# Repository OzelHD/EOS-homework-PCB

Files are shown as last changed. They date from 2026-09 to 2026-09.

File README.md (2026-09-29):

# Generation complete!
# EOS Homework Board

This board is a tutorial follow-along for the EOS homework assignment. It is designed to be a simple board that can be used to learn about PCB design and manufacturing. [Layout Video](https://www.youtube.com/watch?v=nkHFoxe0mrU), [PCB video](https://www.youtube.com/watch?v=PlXd3lLZ4vc)
:)
# Include documentation here




The documentation can be very similar to your wiki article

#Getting started

use `git submodule init && git submodule update --remote --recursive` to get the submodules, and then you can use the project as a normal KiCAD project.

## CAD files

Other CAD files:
PCB/Parts/OzelHD-addition-repo/OzelHD-addition-3D_models/QFN-48-1EP_7x7mm_P0.5mm_EP5.6x5.6mm.step
PCB/Parts/OzelHD-addition-repo/OzelHD-addition-3D_models/Crystal_SMD_MicroCrystal_CC8V-T1A-2Pin_2.0x1.2mm.step
PCB/Parts/OzelHD-addition-repo/OzelHD-addition-3D_models/0530480410.stp
PCB/Parts/OzelHD-addition-repo/OzelHD-addition-3D_models/DLF162500LT-5028A1.STEP

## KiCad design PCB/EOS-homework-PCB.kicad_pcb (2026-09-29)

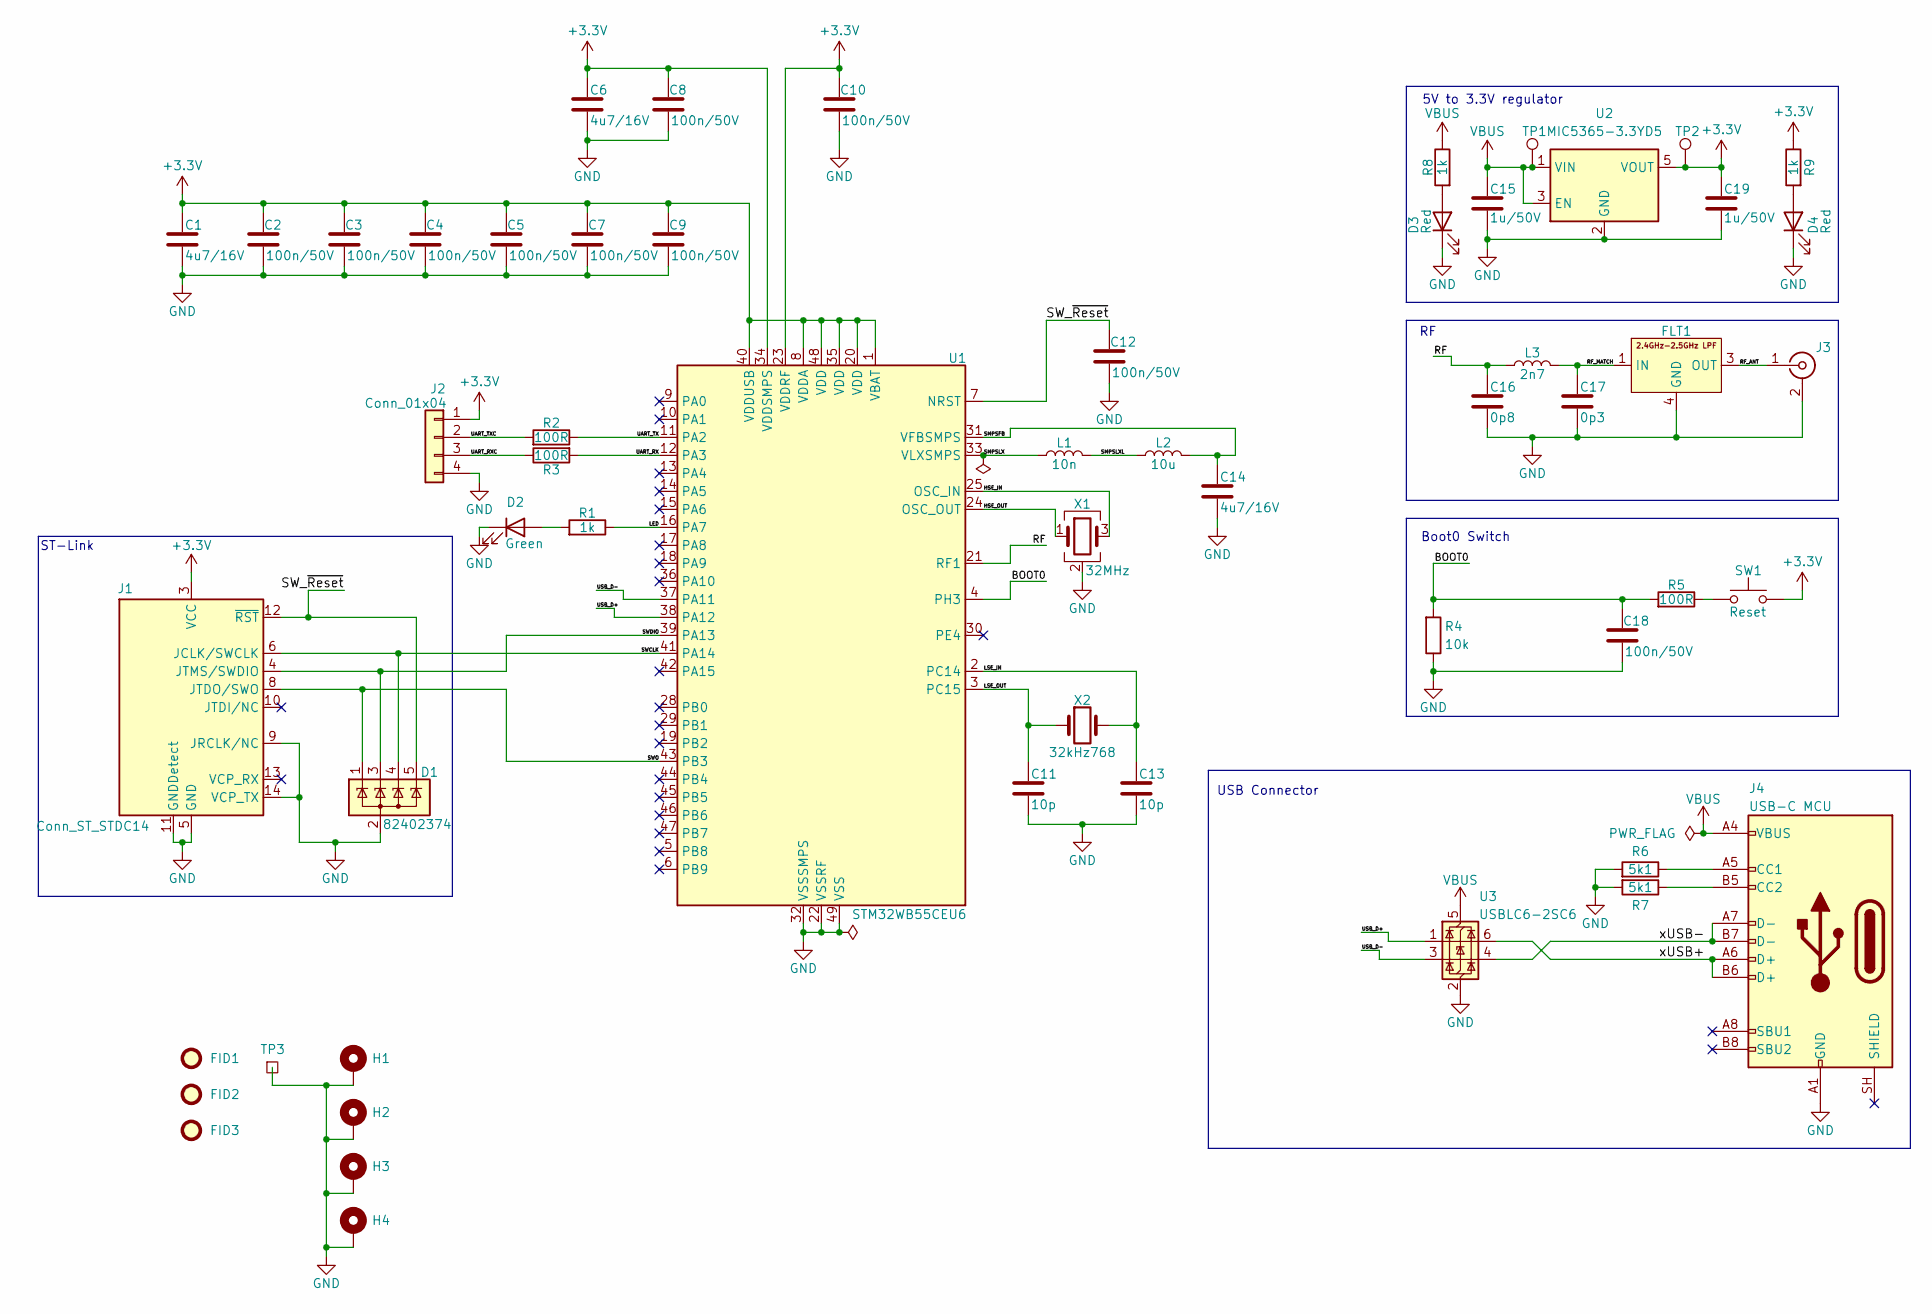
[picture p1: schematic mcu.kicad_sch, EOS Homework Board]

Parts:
C1, C6, C14: 4u7/16V; C_0805_2012Metric; Part No. 885012207053
C2, C3, C4, C5, C7, C8, C9, C10, C12, C18: 100n/50V; C_0603_1608Metric; Part No. 885012206095
C11, C13: 10p; C_0603_1608Metric
C15, C19: 1u/50V; C_0603_1608Metric; Part No. 885012206126
C16: 0p8; C_0603_1608Metric
C17: 0p3; C_0603_1608Metric
D1: 82402374; SOT-353_SC-70-5; Part No. 82402374
D2: Green; LED_0603_1608Metric; Part No. 150060GS75000
D3, D4: Red; LED_0603_1608Metric; Part No. 150060RS75000
FID1, FID2, FID3: Fiducial; Fiducial_1mm_Mask2mm
FLT1: DLF162500LT-5028A1
H1, H2, H3, H4: MountingHole_Pad; MountingHole_2.2mm_M2_Pad_Via
J1: Conn_ST_STDC14; IDC-Header_2x07_P1.27mm_Vertical_SMD; Part No. 62701420621
J2: Conn_01x04; Molex_PicoBlade_53048-0410_1x04_P1.25mm_Horizontal
J3: Conn_Coaxial; U.FL_Hirose_U.FL-R-SMT-1_Vertical
J4: USB-C MCU; USB_C_Receptacle_GCT_USB4105-xx-A_16P_TopMnt_Horizontal; Part No. 629722000214
L1: 10n; L_0402_1005Metric
L2: 10u; L_0805_2012Metric
L3: 2n7; L_0402_1005Metric
R1, R8, R9: 1k; R_0603_1608Metric; Part No. 560112116014
R2, R3, R5: 100R; R_0603_1608Metric; Part No. 560112116009
R4: 10k; R_0603_1608Metric; Part No. 560112116005
R6, R7: 5k1; R_0603_1608Metric; Part No. CRCW06035K10FKEAC
SW1: Reset; SW_Push_Wuerth_434123025826; Part No. 434123025826
TP1, TP2: TestPoint; TestPoint_Pad_D1.0mm
TP3: TestPoint_Square; TestPoint_THTPad_1.5x1.5mm_Drill0.7mm
U1: STM32WB55CEU6; QFN-48-1EP_7x7mm_P0.5mm_EP5.6x5.6mm
U2: MIC5365-3.3YD5; TSOT-23-5
U3: USBLC6-2SC6; SOT-23-6; Part No. 82400102
X1: 32MHz; Crystal_SMD_2016-4Pin_2.0x1.6mm
X2: 32kHz768; Crystal_SMD_2012-2Pin_2.0x1.2mm; Manifacturer Part Number STDMUB1-32.768K

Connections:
+3.3V: C1.1, C2.1, C3.1, C4.1, C5.1, C6.1, C7.1, C8.1, C9.1, C10.1, C19.1, J1.3 (VCC), J2.1, R9.2, SW1.2, TP2.1 (1_1), U1.1 (VBAT), U1.8 (VDDA), U1.20 (VDD), U1.23 (VDDRF), U1.34 (VDDSMPS), U1.35 (VDD), U1.40 (VDDUSB), U1.48 (VDD), U2.5 (VOUT)
/Microcontroller/BOOT0: C18.1, R4.1, R5.1, U1.4 (PH3)
/Microcontroller/HSE_IN: U1.25 (OSC_IN), X1.3
/Microcontroller/HSE_OUT: U1.24 (OSC_OUT), X1.1
/Microcontroller/LED: R1.2, U1.16 (PA7)
/Microcontroller/LSE_IN: C13.1, U1.2 (PC14), X2.2
/Microcontroller/LSE_OUT: C11.1, U1.3 (PC15), X2.1
/Microcontroller/RF: C16.1, L3.1, U1.21 (RF1)
/Microcontroller/RF_ANT: FLT1.3 (OUT), J3.1 (In)
/Microcontroller/RF_MATCH: C17.1, FLT1.1 (IN), L3.2
/Microcontroller/SMPSFB: C14.1, L2.2, U1.31 (VFBSMPS)
/Microcontroller/SMPSLX: L1.1, U1.33 (VLXSMPS)
/Microcontroller/SMPSLXL: L1.2, L2.1
/Microcontroller/SWCLK: D1.4 (K), J1.6 (JCLK/SWCLK), U1.41 (PA14)
/Microcontroller/SWDIO: D1.3 (K), J1.4 (JTMS/SWDIO), U1.39 (PA13)
/Microcontroller/SWO: D1.1 (K), J1.8 (JTDO/SWO), U1.43 (PB3)
/Microcontroller/SW_~Reset: C12.1, D1.5 (K), J1.12 (~RST), U1.7 (NRST)
/Microcontroller/UART_RX: R3.1, U1.12 (PA3)
/Microcontroller/UART_RXC: J2.3, R3.2
/Microcontroller/UART_TX: R2.2, U1.11 (PA2)
/Microcontroller/UART_TXC: J2.2, R2.1
/Microcontroller/USB_D+: U1.38 (PA12), U3.1 (I/O1)
/Microcontroller/USB_D-: U1.37 (PA11), U3.3 (I/O2)
/Microcontroller/xUSB+: J4.A6 (D+), J4.B6 (D+), U3.6 (I/O1)
/Microcontroller/xUSB-: J4.A7 (D-), J4.B7 (D-), U3.4 (I/O2)
GND: C1.2, C2.2, C3.2, C4.2, C5.2, C6.2, C7.2, C8.2, C9.2, C10.2, C11.2, C12.2, C13.2, C14.2, C15.2, C16.2, C17.2, C18.2, C19.2, D1.2 (A), D2.1 (K), D3.1 (K), D4.1 (K), FLT1.2 (GND), FLT1.4 (GND), H1.1 (1_1), H2.1 (1_1), H3.1 (1_1), H4.1 (1_1), J1.5 (GND), J1.7 (GND), J1.9 (JRCLK/NC), J1.11 (GNDDetect), J1.14 (VCP_TX), J2.4, J3.2 (Ext), J4.A1 (GND), J4.A12 (GND), J4.B1 (GND), J4.B12 (GND), R4.2, R6.1, R7.1, TP3.1 (1_1), U1.22 (VSSRF), U1.32 (VSSSMPS), U1.49 (VSS), U2.2 (GND), U3.2 (GND), X1.2 (G), X1.4 (G)
unnamed: D2.2 (A), R1.1
unnamed: D3.2 (A), R8.1
unnamed: D4.2 (A), R9.1
unnamed: J4.A5 (CC1), R6.2
unnamed: J4.B5 (CC2), R7.2
unnamed: R5.2, SW1.1
VBUS: C15.1, J4.A4 (VBUS), J4.A9 (VBUS), J4.B4 (VBUS), J4.B9 (VBUS), R8.2, TP1.1 (1_1), U2.1 (VIN), U2.3 (EN), U3.5 (VBUS)

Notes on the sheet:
Boot0 Switch
ST-Link
USB Connector
5V to 3.3V regulator

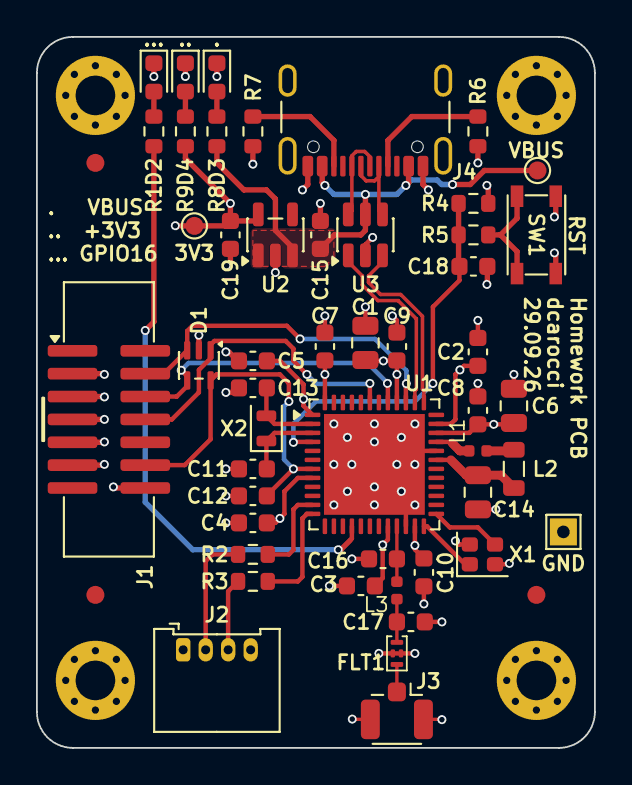
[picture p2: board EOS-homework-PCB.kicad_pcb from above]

Board: 4 copper layers, 31.0 x 39.5 mm, 56 parts (0 on the bottom side), 33 nets.

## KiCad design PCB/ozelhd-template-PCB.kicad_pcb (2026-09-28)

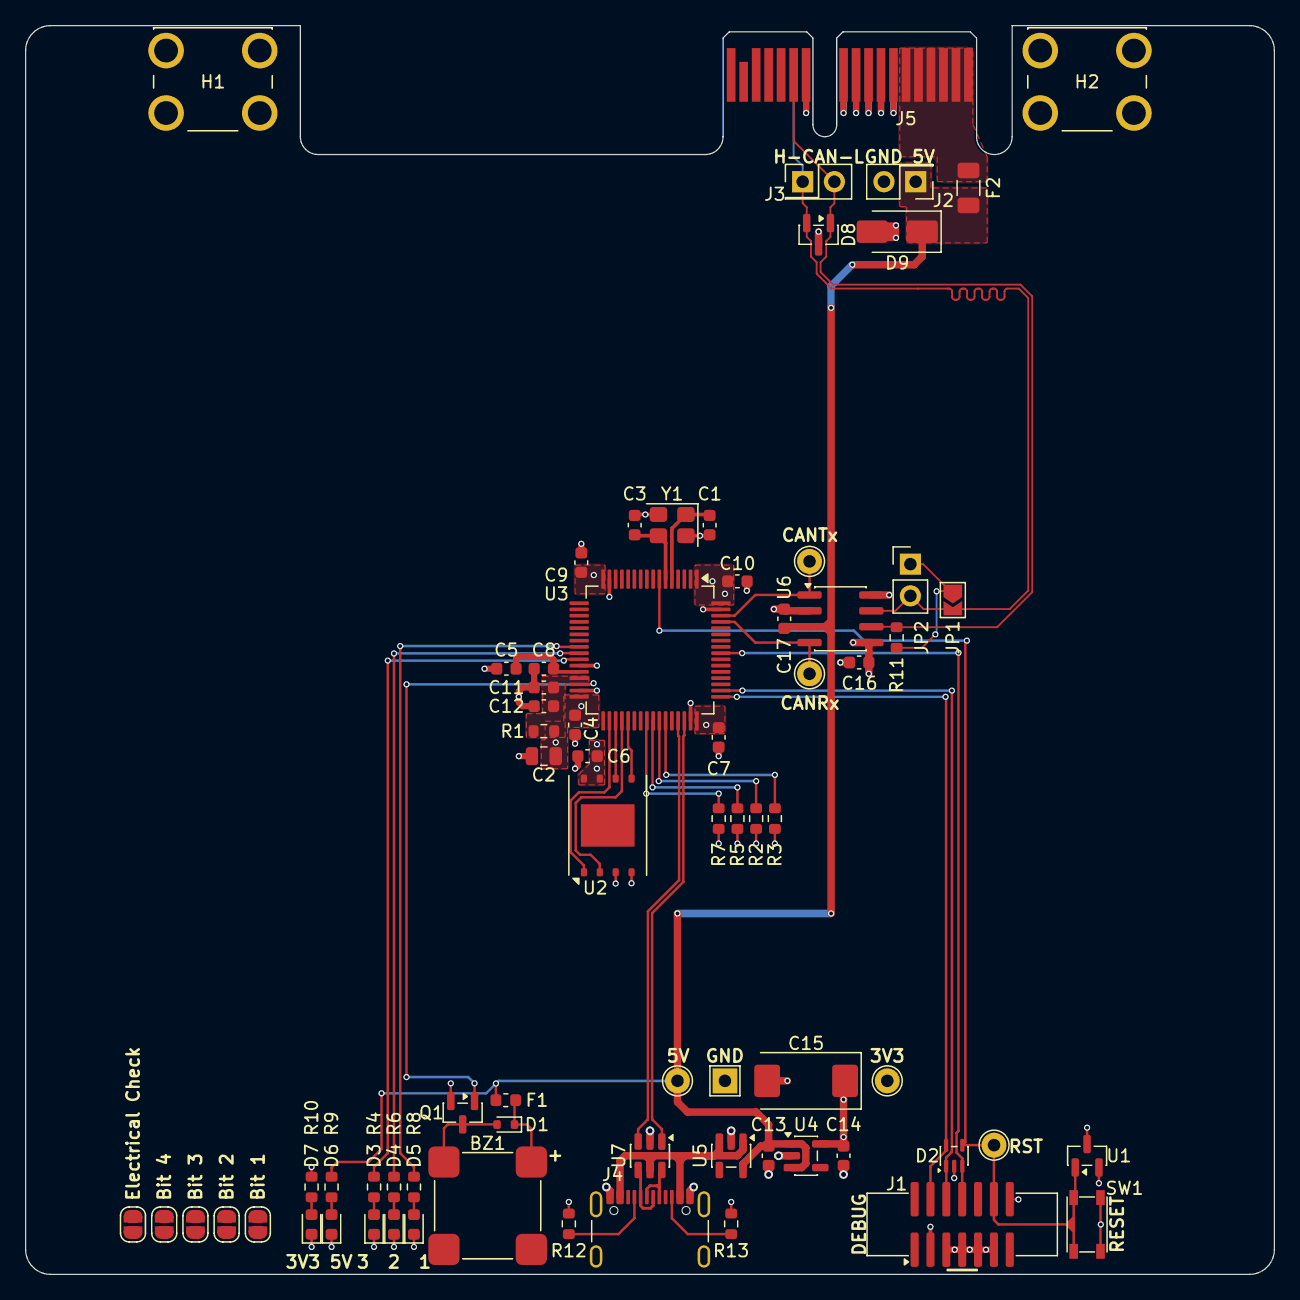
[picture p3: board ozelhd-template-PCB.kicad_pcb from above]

Board: 4 copper layers, 100.0 x 100.0 mm, 72 parts (0 on the bottom side), 43 nets.

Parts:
BZ1: Buzzer; Buzzer_CUI_CMT-8504-100-SMT-TR
C1, C3: 10p/50V; C_0603_1608Metric
C2: 10u/10V; C_0805_2012Metric
C4, C6, C7, C8, C9, C10, C16, C17: 100n/50V; C_0603_1608Metric
C5, C12, C13, C14: 1u/16V; C_0603_1608Metric
C11: 10n/50V; C_0603_1608Metric
C15: 100u/6.3V; CP_EIA-7343-20_Kemet-V
D1: 10V; D_SOD-523
D2: 82402374; SOT-353_SC-70-5
D3, D6, D7: Red; LED_0603_1608Metric
D4: Yellow; LED_0603_1608Metric
D5: Green; LED_0603_1608Metric
D8: CAN TVS; SOT-23
D9: 5.0V; D_SMA
F1: 250mA/9V; Fuse_0603_1608Metric
F2: 1A/6V; Fuse_1206_3216Metric
H1, H2: 7790_NC; Mounting_Keystone_7790_NC
J1: STDC-14 Debug; IDC-Header_2x07_P1.27mm_Vertical_SMD
J2: 5V; PinHeader_2x01_P2.54mm_Vertical
J3: CAN; PinHeader_2x01_P2.54mm_Vertical
J4: USB-C MCU; USB_C_Receptacle_GCT_USB4105-xx-A_16P_TopMnt_Horizontal
J5: EdgeConn_FC; BUS_PCIexpress_x1
JP1: Termination; SolderJumper-2_P1.3mm_Open_TrianglePad1.0x1.5mm
JP2: DebugTermination; PinHeader_1x02_P2.54mm_Vertical
JP3: Assembly Done; SolderJumper-2_P1.3mm_Open_RoundedPad1.0x1.5mm
JP4: Numbering 1; SolderJumper-2_P1.3mm_Open_RoundedPad1.0x1.5mm
JP5: Numbering 2; SolderJumper-2_P1.3mm_Open_RoundedPad1.0x1.5mm
JP6: Numbering 3; SolderJumper-2_P1.3mm_Open_RoundedPad1.0x1.5mm
JP7: Numbering 4; SolderJumper-2_P1.3mm_Open_RoundedPad1.0x1.5mm
Q1: 2N7002; SOT-23
R1: 0R; R_0603_1608Metric
R2, R3, R5, R7: 2k2; R_0603_1608Metric
R4, R6, R8, R9, R10: 1k; R_0603_1608Metric
R11: 120R; R_0603_1608Metric
R12, R13: 5k1; R_0603_1608Metric
SW1: Reset; SW_Push_Wuerth_434123025826
TP1, TP2, TP3, TP4, TP5: TestPoint; TestPoint_THTPad_D2.0mm_Drill1.0mm
TP6: TestPoint; TestPoint_THTPad_2.0x2.0mm_Drill1.0mm
U1: ADM1818; SOT-23
U2: W25N512GVEIG; WSON-8-1EP_8x6mm_P1.27mm_EP3.4x4.3mm
U3: STM32G473RCTx; LQFP-64_10x10mm_P0.5mm
U4: AP2112K-3.3; SOT-23-5
U5: MAX40200AUK; SOT-23-5
U6: MCP2562-E-SN; SOIC-8_3.9x4.9mm_P1.27mm
U7: USBLC6-2SC6; SOT-23-6
Y1: 16MHz/8pF; Crystal_SMD_3225-4Pin_3.2x2.5mm

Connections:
+3.3V: C2.1, C4.1, C6.1, C7.1, C9.1, C10.1, C14.1, C15.1, C16.1, J1.3 (VCC), R1.2, R2.1, R3.1, R5.1, R7.1, R10.1, TP2.1 (1_1), U1.2 (VCC), U2.3 (~WP(IO2)), U2.7 (~HOLD(IO3)), U2.8 (VCC), U3.1 (VBAT), U3.16 (VDD), U3.32 (VDD), U3.48 (VDD), U3.64 (VDD), U4.5 (VOUT), U6.5 (Vio)
+3.3VA: C11.1, C12.1, R1.1, U3.29 (VDDA)
+5V: C13.1, C17.1, D9.1 (K), F1.1, F2.1, J2.1, R9.2, TP5.1 (1_1), U4.1 (VIN), U4.3 (EN), U5.5 (OUT), U6.3 (VDD)
/Backplane connector, mounting/5V_prefuse: F2.2, J5.B1 (5V), J5.B2 (5V), J5.B3 (5V), J5.B4 (5V), J5.B5 (5V), J5.B6 (5V)
/Backplane connector, mounting/CANH: D8.2 (K), J3.1, J5.A13 (CANH), JP1.2 (B), JP2.2 (B), U6.7 (CANH)
/Backplane connector, mounting/CANL: D8.1 (K), J3.2, J5.B13 (CANL), R11.1, U6.6 (CANL)
/CAN Transceiver/CAN.Rx: TP3.1 (1_1), U3.61 (PB8), U6.4 (RXD)
/CAN Transceiver/CAN.Tx: TP4.1 (1_1), U3.62 (PB9), U6.1 (TXD)
/Microcontroller/Buzzer_PWM: Q1.1 (G), U3.30 (PB10)
/Microcontroller/I2C2.SCL: R3.2, U3.43 (PA9)
/Microcontroller/I2C2.SDA: R2.2, U3.42 (PA8)
/Microcontroller/I2C3.SCL: R7.2, U3.40 (PC8)
/Microcontroller/I2C3.SDA: R5.2, U3.41 (PC9)
/Microcontroller/LED1: R8.1, U3.24 (PB0)
/Microcontroller/LED2: R6.1, U3.25 (PB1)
/Microcontroller/LED3: R4.1, U3.26 (PB2)
/Microcontroller/OSC_IN: C1.1, U3.5 (PF0), Y1.1
/Microcontroller/OSC_OUT: C3.1, U3.6 (PF1), Y1.3
/Microcontroller/SPI2.CS: U2.1 (~CS), U3.34 (PB12)
/Microcontroller/SPI2.MISO: U2.2 (DO(IO1)), U3.36 (PB14)
/Microcontroller/SPI2.MOSI: U2.5 (DI(IO0)), U3.37 (PB15)
/Microcontroller/SPI2.SCK: U2.6 (CLK), U3.35 (PB13)
/Microcontroller/SWCLK: D2.1 (K), J1.6 (JCLK/SWCLK), U3.50 (PA14)
/Microcontroller/SWDIO: D2.5 (K), J1.4 (JTMS/SWDIO), U3.49 (PA13)
/Microcontroller/SWO: D2.3 (K), J1.8 (JTDO/SWO), U3.56 (PB3)
/Microcontroller/USB+: U3.46 (PA12), U7.1 (I/O1)
/Microcontroller/USB-: U3.45 (PA11), U7.3 (I/O2)
/Microcontroller/VREF: C5.1, C8.1, U3.28 (VREF+)
/Microcontroller/~Reset: D2.4 (K), J1.12 (~RST), SW1.1, TP1.1 (1_1), U1.1 (~RESET), U3.7 (PG10)
/USB Connector/xUSB+: J4.A6 (D+), J4.B6 (D+), U7.6 (I/O1)
/USB Connector/xUSB-: J4.A7 (D-), J4.B7 (D-), U7.4 (I/O2)
GND: C1.2, C2.2, C3.2, C4.2, C5.2, C6.2, C7.2, C8.2, C9.2, C10.2, C11.2, C12.2, C13.2, C14.2, C15.2, C16.2, C17.2, D2.2 (A), D3.1 (K), D4.1 (K), D5.1 (K), D6.1 (K), D7.1 (K), D8.3 (A), D9.2 (A), J1.5 (GND), J1.7 (GND), J1.9 (JRCLK/NC), J1.11 (GNDDetect), J1.14 (VCP_TX), J2.2, J4.A1 (GND), J4.A12 (GND), J4.B1 (GND), J4.B12 (GND), J5.A7 (GND), J5.A8 (GND), J5.A9 (GND), J5.A10 (GND), J5.A11 (GND), J5.A12 (GND), J5.B7 (GND), J5.B8 (GND), J5.B9 (GND), J5.B10 (GND), J5.B11 (GND), J5.B12 (GND), Q1.2 (S), R12.1, R13.1, SW1.2, TP6.1 (1_1), U1.3 (GND), U2.4 (GND), U3.15 (VSS), U3.27 (VSSA), U3.31 (VSS), U3.47 (VSS), U3.63 (VSS), U4.2 (GND), U5.2 (GND), U6.2 (VSS), U6.8 (STBY), U7.2 (GND), Y1.2, Y1.4
unnamed: BZ1.1 (+), D1.1 (K), F1.2
unnamed: BZ1.2 (-), D1.2 (A), Q1.3 (D)
unnamed: D3.2 (A), R4.2
unnamed: D4.2 (A), R6.2
unnamed: D5.2 (A), R8.2
unnamed: D6.2 (A), R9.1
unnamed: D7.2 (A), R10.2
unnamed: J4.A5 (CC1), R12.2
unnamed: J4.B5 (CC2), R13.2
unnamed: JP1.1 (A), JP2.1 (A), R11.2
VBUS: J4.A4 (VBUS), J4.A9 (VBUS), J4.B4 (VBUS), J4.B9 (VBUS), U5.1 (VDD), U5.3 (EN), U7.5 (VBUS)

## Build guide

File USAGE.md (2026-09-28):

# Refresh ~1min after repo generation!
# HERMES PCB template repo
**IMPORTANT:** If you are using this after HERMES, some details have to be changed, such as the BOM merge trigger in the export workflow!
## Usage:
1. Create a repository using this repo as a template, and name the new repo accordingly for your board
1. A KiCAD project will be automaticaly generated from this template by a github workflow
1. **IMPORTANT: WAIT FOR THE WORKFLOW TO COMPLETE** - You will see a commit by github-actions[bot]

## Naming rules for new repo:
1. Name should follow this structure:
   **[project-name]-[pcb-name]-PCB**
1. everywhere dashes (`-`) are used where spaces would be
1. **project-name:** name of the project, lowercase (ex.: `bernoulli`)
1. **pcb-name:** name of the pcb
    - lowercase
    - preferably short-ish, but *not* abbreviation, dash (-) instead of spaces (i.e. `flight-computer`, or `power`, but **not** ~~`fc`~~, and **not** ~~`pwr`~~)
    - must **not** include `board` (i.e. `power`, but **not** ~~`power-board`~~)
1. Ends with `PCB`, uppercase
1. The name of the project will be the same as the name of the repo

### Correct repo name examples:
- `bernoulli-power-PCB`
- `nicollier-flight-computer-PCB`
- `nicollier-backplane-PCB`
- `hermes-recovery-PCB`

## Repo structure:
**Suppose the name of the repo is `bernoulli-beer-PCB`, the repo structure would be the following:**
```
├── Datasheets/
├── bernoulli-beer-blockdiagram.drawio
├── bernoulli-beer-blockdiagram.pdf
├── PCB/
│   ├── ARIS_frame.kicad_wks
│   ├── can.kicad_sch
│   ├── bernoulli-beer-PCB.kicad_pcb
│   ├── bernoulli-beer-PCB.kicad_prl
│   ├── bernoulli-beer-PCB.kicad_pro
│   ├── bernoulli-beer-PCB.kicad_sch
│   ├── mcu.kicad_sch
│   ├── Outputs/
│   ├── Parts/
│   │   ├── kicad-extra-repo/
│   │   └── kicad-standard-repo/
│   ├── power.kicad_sch
│   ├── stack_format.kicad_sch
│   └── usb.kicad_sch
├── README.md
```

### Datasheets/
Put some useful datasheets here that are helpful for understanding the PCB design
### -blockdiagram.drawio
Put the blockdiagram of the PCB here, and **keep it up-to-date!**
### -blockdiagram.pdf
The blockdiagram exported to pdf, also, very-very important, **keep it up-to-date!!!**
### PCB/
The KiCAD project lives here, some important contents:
#### PCB/Outputs/
A github workflow will automatically export the schematics as PDF, the BOM in CSV, iBOM in HTML, and the PCB as STEP here.
#### PCB/Parts/
This directory contains all the extra symbol and footprint libraries that you might add, as well as the kicad-standard-repo and the kicad-extra-repo. The latter two are maintained by ARIS, and are included here as git submodules, you must not modify them! (git submodule init && git submodule update --remote --recursive)
### README.md
This file contains the description of the PCB. Best README file in every project cycle gets a beer (or sth else) from Zoltán. Give a good, but brief overview, you can also include images here (for that you should make an `Images/` directory and put them there), etc. Usually this can be quite similar to the wiki article you write.

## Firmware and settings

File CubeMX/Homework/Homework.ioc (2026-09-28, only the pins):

Mcu.UserName=STM32WB55CEUx
PA11.Signal=USB_DM
PA12.Signal=USB_DP
PA13.Signal=SYS_JTMS-SWDIO
PA14.Signal=SYS_JTCK-SWCLK
PA2.Signal=LPUART1_TX
PA3.Signal=LPUART1_RX
PA7.Signal=S_TIM17_CH1
PB3.Signal=SYS_JTDO-SWO
PC14-OSC32_IN.Signal=RCC_OSC32_IN
PC15-OSC32_OUT.Signal=RCC_OSC32_OUT

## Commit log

2026-09-28 Generate project from template
    [EOS-homework-PCB.kicad_pcb, EOS-homework-PCB.kicad_sch, can.kicad_sch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]
2026-09-28 Schematic done
    [DLF162500LT-5028A1.STEP, EOS-homework-PCB.kicad_pcb, EOS-homework-PCB.kicad_sch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]
2026-09-29 added usb sheet back
    [usb.kicad_sch]
2026-09-29 PCB done.
    [0530480410.stp, Crystal_SMD_MicroCrystal_CC8V-T1A-2Pin_2.0x1.2mm.step, EOS-homework-PCB.kicad_pcb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]
2026-09-29 added gnd under antenna connection
    [EOS-homework-PCB.kicad_pcb]
